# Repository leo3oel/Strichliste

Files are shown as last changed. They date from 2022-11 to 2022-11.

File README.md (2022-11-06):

# Strichliste
Digitale Variante einer Strichliste mit einem Arduino Uno.
Main-Programm: Strichliste.ino

## Funktionen
 - Sortieren nach Namen
 - Speichern der Striche auf dem EEPROM
 - Hinzufügen/Löschen von Personen über SD-Karte
 - Stromsparmodus
 - Backup auf SD-Karte

## Dependencies
- [Pin Library](https://github.com/leo3oel/pin) zur erkennung von Flanken, etc.

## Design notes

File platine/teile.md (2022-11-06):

# Verwendete Teile

|Typ|Preis|Link|
|---|----|---|
|Arduino Nano every|10.40€|[Nano Every](https://store.arduino.cc/products/arduino-nano-every?queryID=undefined)|
|LCD Display |5.38€|[JOY-IT LCD-Modul 16x2](https://www.pollin.de/p/joy-it-lcd-modul-16x2-121738)|
|Drehknopf|2.45€|[DEBO ENCODER](https://www.reichelt.de/entwicklerboards-drehwinkel-encoder-ky-040-debo-encoder-p282545.html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)|
|Mutter für Drehknopf|0.29€|[P4-MUTTER](https://www.reichelt.de/index.html?ACTION=446&LA=3&nbc=1&q=p4-mutter%20)|
|Abdeckung Drehknopf|0.60€|[Drehknopf 27x15mm](https://www.pollin.de/p/drehknopf-oe27x15-mm-achse-oe6-mm-410188)|
|Miniaturtaster gelb|0.62€|[T 250A GE](https://www.reichelt.de/miniatur-drucktaster-0-5a-24vac-1x-ein-ge-t-250a-ge-p19984.html?&trstct=pos_0&nbc=1)|
|Miniaturtaster grün|0.62€|[T 250A GN](https://www.reichelt.de/miniatur-drucktaster-0-5a-24vac-1x-ein-gn-t-250a-gn-p19985.html?&trstct=vrt_pdn&nbc=1)|
|Miniaturtaster rot|0.74€|[T 250A RT](https://www.reichelt.de/miniatur-drucktaster-0-5a-24vac-1x-ein-rt-t-250a-rt-p31772.html?&trstct=vrt_pdn&nbc=1)|
|Micro SD Slot|1.55€|[DEBO MICROSD 2](https://www.reichelt.de/entwicklerboards-breakout-board-fuer-microsd-karten-debo-microsd-2-p266045.html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)|

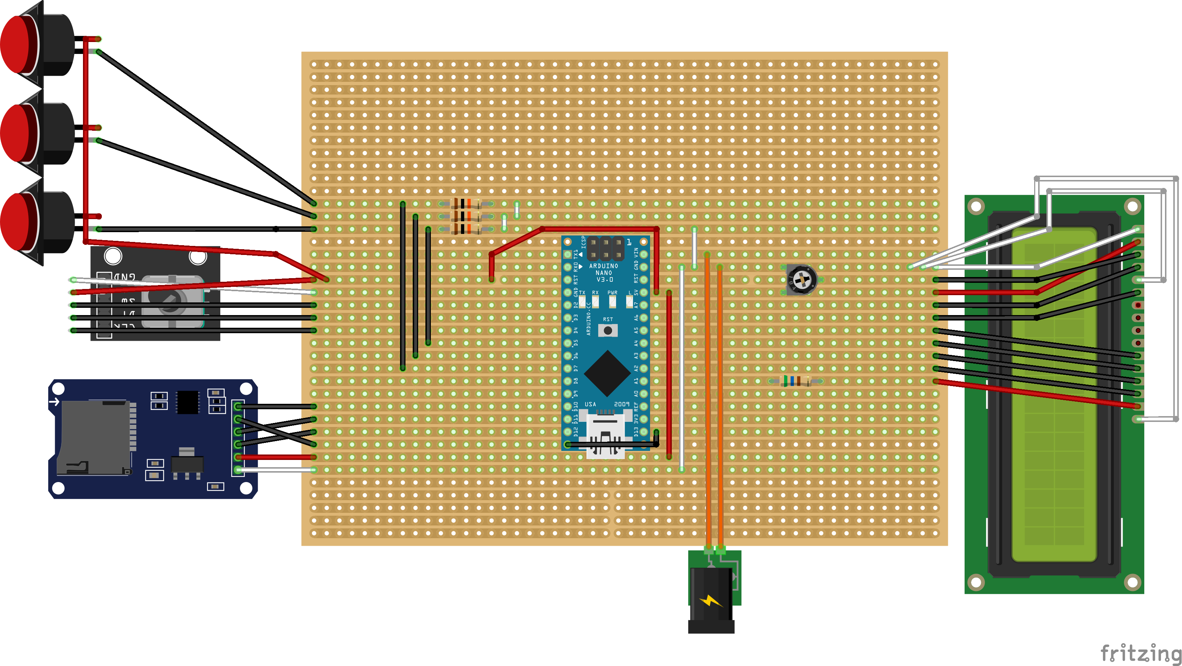
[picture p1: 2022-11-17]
platine/Steckplatine.png

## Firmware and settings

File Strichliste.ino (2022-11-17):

#include <LiquidCrystal.h>
#include "direction.h"
#include "sleep.h"

#ifndef _PIN_H
#define _PIN_H
#include <pin.h> //Custom Pin Library https://github.com/leo3oel/pin
#endif

#ifndef _OWNSD_H
#define _OWNSD_H
#include "ownsd.h"
#endif

#ifndef _ARRAY_H
#define _ARRAY_H
#include "array.h"
#endif

#ifndef ARRAYSIZES
#define ARRAYSIZE 60
#define STRINGLENGTH 12
#endif

#define interruptPin 2

// Variablen und Konstanten
const unsigned short lcdRS = 8, lcdEN = 9, lcdD4 = 19, lcdD5 = 18, lcdD6 = 17, lcdD7 = 16; // LCD Pins
DigitalPin LCDled(15, OUTPUT);
LiquidCrystal lcd(lcdRS, lcdEN, lcdD4, lcdD5, lcdD6, lcdD7);

// Pins
Direction drehgeber(4, 3, 2);
DigitalPin StrichePlus(5, INPUT), StricheMinus(6, INPUT), StricheReset(7, INPUT);
unsigned long inactivity = 0; // sleeptimer
const short disteeprom = 2;   // distance between persons in EEPROM

// Current Position in List
short PosInList = -1;    // Current position in List, -1 => display "make a selection"
short prevPosInList = 0; // Previous position in List

// Arrays for Striche/Names
unsigned short strichearray[ARRAYSIZE];   //= {6,0,12,0,1,0,0};//Striche
char namesarray[ARRAYSIZE][STRINGLENGTH]; //= {"Leonhard S", "Rainer S", "Sophie S", "Simon M"}; // Array mit all Names, max 12 Characters per Name
unsigned short poseeTOposlcd[ARRAYSIZE];  // Enthält an Position 0 Nummer von erstem Namen
short usedpers = 0;                       // Currently used Places in Array

void setup() // Setup
{
    lcd.begin(16, 2);
    LCDled.setOut(HIGH);
    // EEPROM lesen
    readEEPROM(strichearray); // Striche vom EEPROM lesen
    bool sdread = readSD(namesarray); //read Names from SD
    if (sdread)               // check if reading was successful
    {
        // everything ok
    }
    else
    {

        lcd.println(F("SD-Karten Fehler"));
        delay(2000);
        LCDled.setOut(LOW); // turn off led
        while (true)
        {
            delay(100000); // do nothing
        }
    }
    usedpers = countarraylength(namesarray); // Anzahl der Benutzten stellen zählen
    sort(namesarray, poseeTOposlcd);  
    pinMode(interruptPin, INPUT); // Pin for wakeup
    lcd.print(F("Name:"));
    lcd.setCursor(8, 0);
    lcd.print(F("Striche:"));
    lcd.setCursor(0, 1);
    lcd.print(F("Bitte auswaehlen"));
}

void loop()
{
    // sleep inactivity abfrage nach gefühl
    if (inactivity > 20000) // Nach ca. 20s
    {
        inactivity = 0;
        PosInList = -1;
        sendToSleep(namesarray, strichearray);
        lcd.setCursor(0, 1);
        lcd.print(F("Bitte auswaehlen"));
    }

    // Hoch/runter schalten
    if (drehgeber.turnedClockwise()) // PosInList durchwählen positiv
    {
        inactivity = 0;
        PosInList++;
    }

    if (drehgeber.turnedCounterClockwise()) // PosInList durchwählen negativ
    {
        inactivity = 0;
        PosInList--;
    }

    if (PosInList >= usedpers) // Ende erreicht
        PosInList = -1;
    if (PosInList < -1)
        PosInList = usedpers - 1;
    if (PosInList != prevPosInList) // Neuen PosInList anzeigen
        schreiben(PosInList, poseeTOposlcd);

    // Striche hoch/runterzählen/zurücksetzen
    if (StrichePlus.posEDGE()) // Zugehörige Striche hochzählen
    {
        inactivity = 0;

        // EEPROM lesen
        strichearray[poseeTOposlcd[PosInList]] = EEPROM.read(poseeTOposlcd[PosInList] * disteeprom);
        strichearray[poseeTOposlcd[PosInList]]++;
        // EEPROM schreiben
        EEPROM.update((poseeTOposlcd[PosInList]) * disteeprom, strichearray[poseeTOposlcd[PosInList]]);
        schreiben(PosInList, poseeTOposlcd);
    }

    if (StricheMinus.posEDGE()) // Zugehörige Striche hochzählen
    {
        inactivity = 0;

        // EEPROM lesen
        strichearray[poseeTOposlcd[PosInList]] = EEPROM.read(poseeTOposlcd[PosInList] * disteeprom);
        if (strichearray[poseeTOposlcd[PosInList]] > 0) // Keine negativen Zahlen zulassen
        {
            strichearray[poseeTOposlcd[PosInList]]--;
            // EEPROM schreiben
            EEPROM.update((poseeTOposlcd[PosInList]) * disteeprom, strichearray[poseeTOposlcd[PosInList]]);
            schreiben(PosInList, poseeTOposlcd);
        }
    }

    if (StricheReset.posEDGE() && PosInList >= 0) // Striche zurücksetzen
    {
        inactivity = 0;
        bool reset = 0;
        short int i = 0;

        lcd.clear();
        lcd.setCursor(4, 0);
        lcd.print(F("ACHTUNG!"));
        lcd.setCursor(0, 1);
        lcd.print(strichearray[poseeTOposlcd[PosInList]]);
        lcd.setCursor(4, 1);
        lcd.print(F("EUR bezahlt?"));
        delay(1500); // 2sec delay
        lcd.clear();
        lcd.setCursor(2, 0);
        lcd.print(F("Zum loeschen"));
        lcd.setCursor(0, 1);
        lcd.print(F("erneut druecken"));
       // 3 sec delay, danach erneute abfrage ob noch gedrückt
        while (!reset && i < 100) // Entweder reset oder 2 sec warten
        {
            reset = StricheReset.posEDGE();
            if (reset)
                strichearray[poseeTOposlcd[PosInList]] = 0;
            delay(20);
            i++;
        }
        schreiben(PosInList, poseeTOposlcd);
        EEPROM.update((poseeTOposlcd[PosInList]) * disteeprom, strichearray[poseeTOposlcd[PosInList]]);
    }

    prevPosInList = PosInList;
    inactivity++;
    delay(2); // 20ms delay
}

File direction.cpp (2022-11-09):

#include "direction.h"

Direction::Direction(unsigned short int nclk, unsigned short int ndt, unsigned short int nsw)
{
    clk = nclk;
    dt = ndt;
    sw = nsw;
    pinMode(clk, INPUT);
    pinMode(dt, INPUT);
    pinMode(sw, INPUT);
    digitalWrite(sw, HIGH);
    digitalWrite(dt, HIGH);
    digitalWrite(clk, HIGH);
}


bool Direction::turnedClockwise()
{
    prevStateclkCW = stateclkCW;
    stateclkCW = digitalRead(clk);
    statedtCW = digitalRead(dt);
    if(prevStateclkCW == 1 && stateclkCW == 0 && statedtCW == 1)
    {
        return 1;
    }
    else
    {
        return 0;
    }
}

bool Direction::turnedCounterClockwise()
{
    prevStatedtCCW = statedtCCW;
    stateclkCCW = digitalRead(clk);
    statedtCCW = digitalRead(dt);
    if(prevStatedtCCW == 1 && statedtCCW == 0 && stateclkCCW == 1)
    {
        return 1;
    }
    else
    {
        return 0;
    }
}

bool Direction::buttonState()
{
    bool buttonState = digitalRead(sw);
    return buttonState;
}

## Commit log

2022-10-29 switched int to bool
2022-10-30 switched int to unsigned short int
    [Strichliste.ino]
2022-10-30 changed interrupt to RISING
2022-10-30 fixed going backwards in list
    [Strichliste.ino]
2022-10-30 changed interrupt pin
2022-10-31 updated Pin/Variable names and comments
2022-11-02 added Fritzing file for platine
    [Platine.fzz]
2022-11-02 pin header
2022-11-02 finished class pin
2022-11-02 created a extra library see here: https://github.com/leo3oel/pin
2022-11-02 changed pins to library pin
2022-11-02 fixed infinite refreshing on lcd
    [Strichliste.ino, lcd.ino]
2022-11-03 SD Card function seems to work, arduino ram is full
2022-11-04 changed int to short
    [Strichliste.ino, lcd.ino]
2022-11-06 platinen layout
    [Platine.fzz, platine_breadboard_only.fzz]
2022-11-07 updated breadboard
    [platine_breadboard_only.fzz]
2022-11-17 built in housing
    [platine_breadboard_only.fzz]
